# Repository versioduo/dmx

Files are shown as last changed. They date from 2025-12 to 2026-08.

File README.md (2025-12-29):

# dmx
🚥 MIDI to DMX Controller

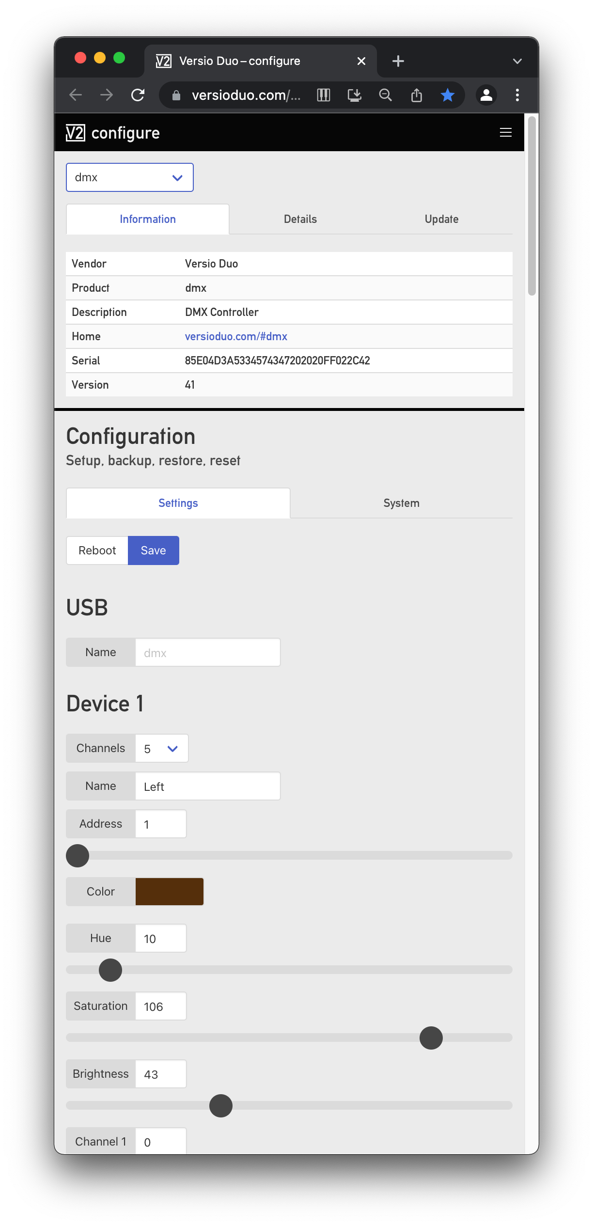
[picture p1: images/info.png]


## Configuration
Up to 16 DMX devices are mapped to 16 MIDI channels. The DMX
devices are configured by their base DMX address and the number
of DMX channels to control.

Default power-on values can be stored in the configuration. A MIDI
_System-Reset_ message will reset all devices and channels to their
configured power-on values.

For RGB devices, it is possible to use a separate set of more
intuitive CC values to control _Brightness_, _Colour_, _Saturation_;
the controller will calculate the RGB channel values accordingly.

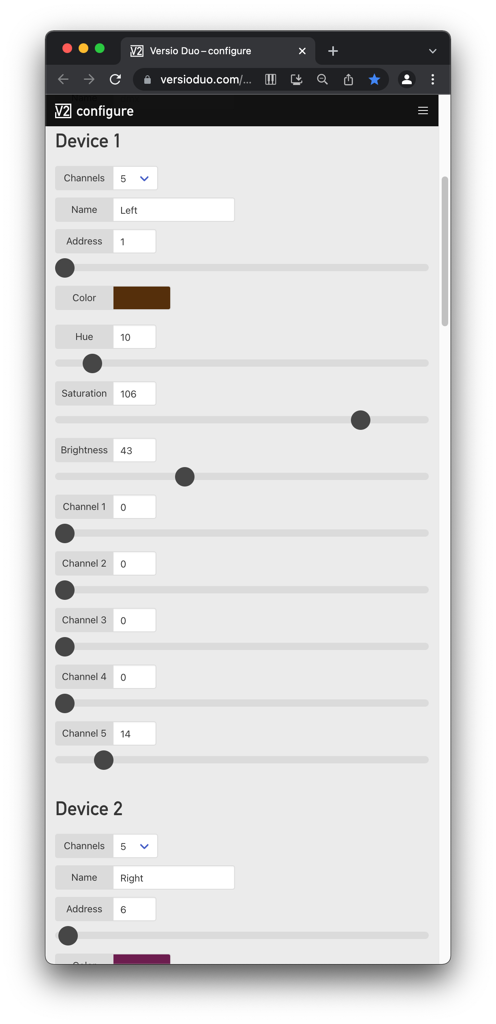
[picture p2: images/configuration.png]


## Controllers
MIDI Control Change (CC) values control the DMX channel values.

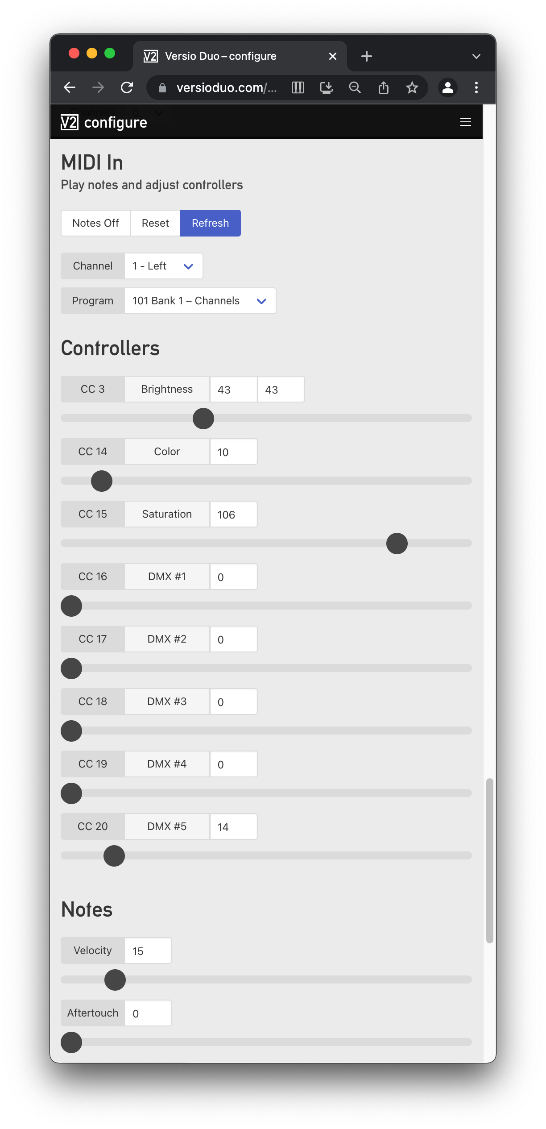
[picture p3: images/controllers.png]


## Notes
The velocity value of a note overwrites the corresponding CC value
for the duration of the note; a MIDI _Note-Off_ will reset the DMX channel
value to the current CC value. A MIDI _All-Notes-Off_ message will restore
all devices and channels to the currently configured controller values.

During an active note, channel aftertouch will change the _Brightness_,
pitch bend will change the _Colour_.

There are two programs (MIDI _Program Change_) for notes. _Channels_
maps a range of consecutive notes to DMX channels.

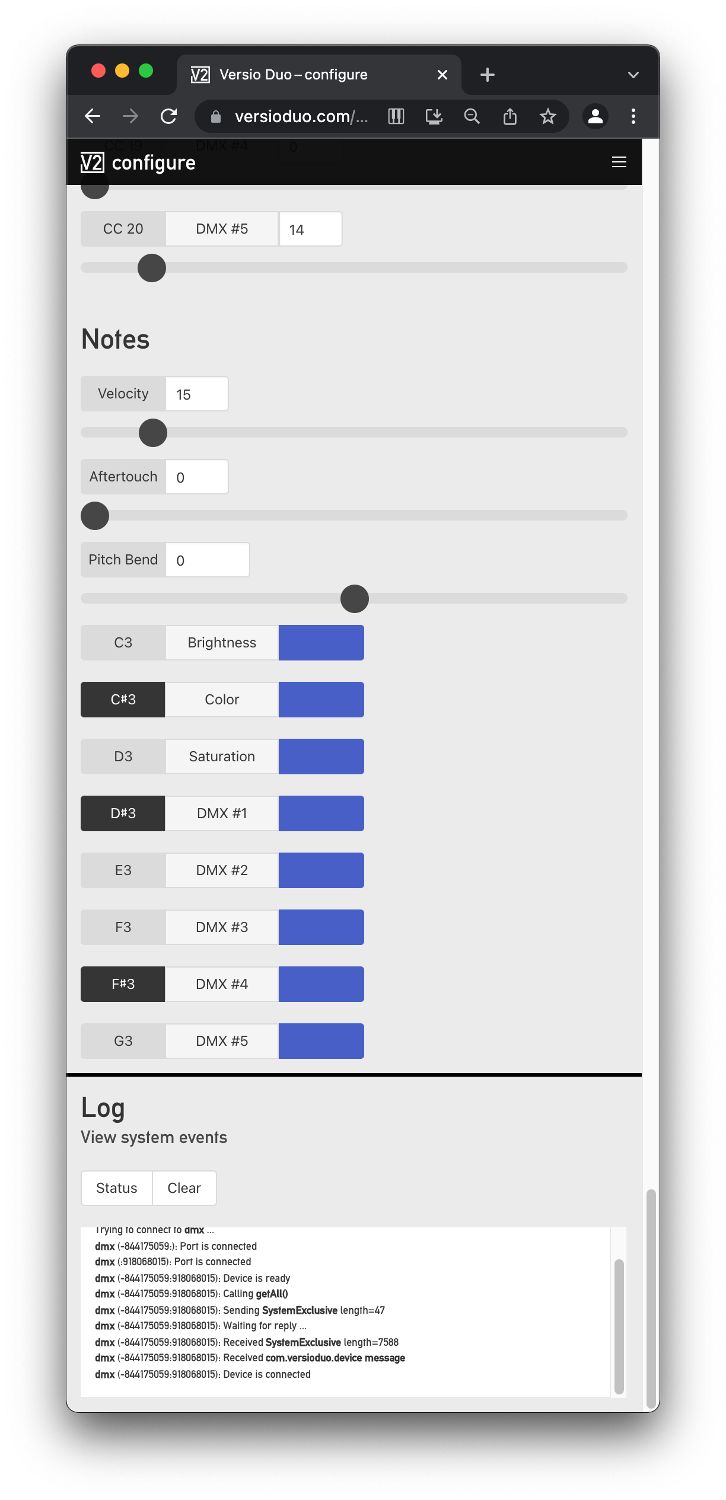
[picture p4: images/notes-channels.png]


_Brightness_ maps all received notes (the pitch is ignored) to control
only the brightness (or the first DMX channel of the device) of the DMX device.
If multiple notes are played at the same time, a MIDI _Note-Off_ will restore
the value of the earlier, still active note.

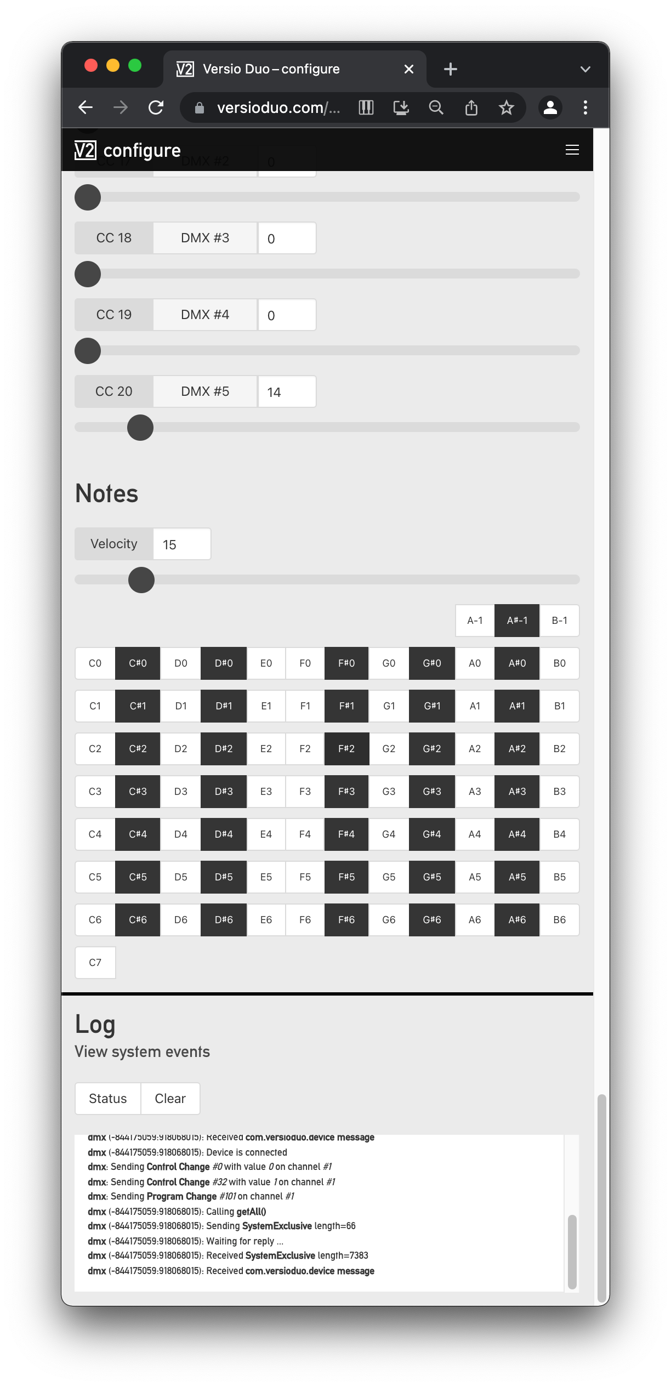
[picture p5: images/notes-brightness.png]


## Max For Live Device
An optional Ableton Max4Live [device](https://github.com/versioduo/max4live)
allows the the direct mapping from Live Automation to DMX values.

To avoid inconsistencies it will monitor the Live transport state, and update
all configured DMX channels of the current device every time _Play_ or
_Stop_ are triggered.

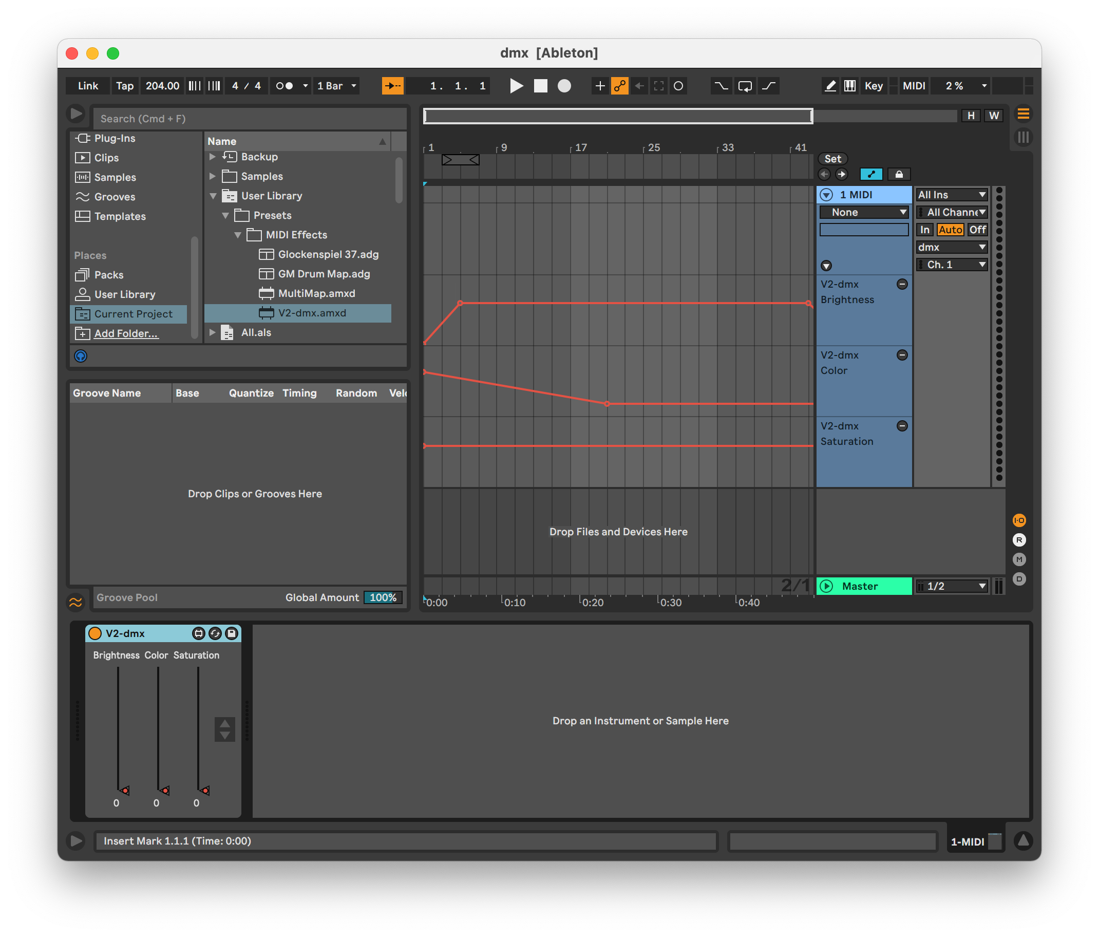
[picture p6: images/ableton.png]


## Hardware
Schematics / PCB

# Copying
Anyone can use this public domain work without having to seek authorisation, no one can ever own it.

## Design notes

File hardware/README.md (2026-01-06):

# dmx-hardware

🚥 MIDI to DMX Bridge

## Board

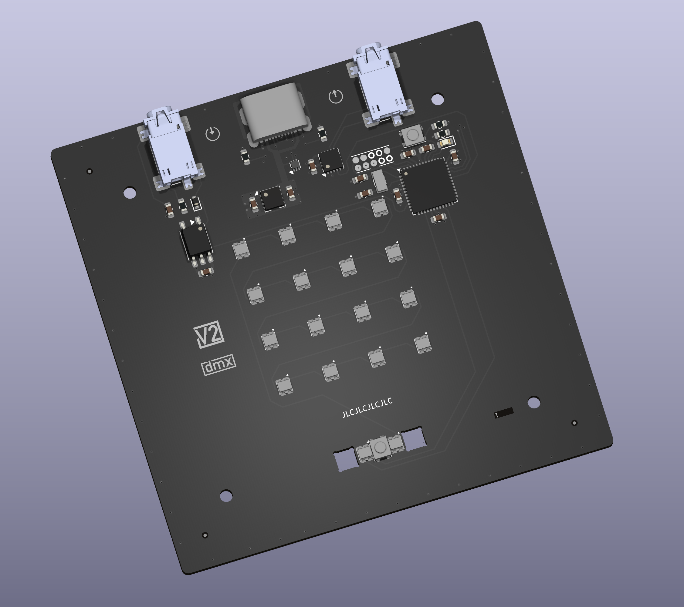
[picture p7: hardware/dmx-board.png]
board


## Schematic

[PDF](dmx.pdf)

## Bill Of Materials

[Interactive BOM](https://versioduo.com/view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)

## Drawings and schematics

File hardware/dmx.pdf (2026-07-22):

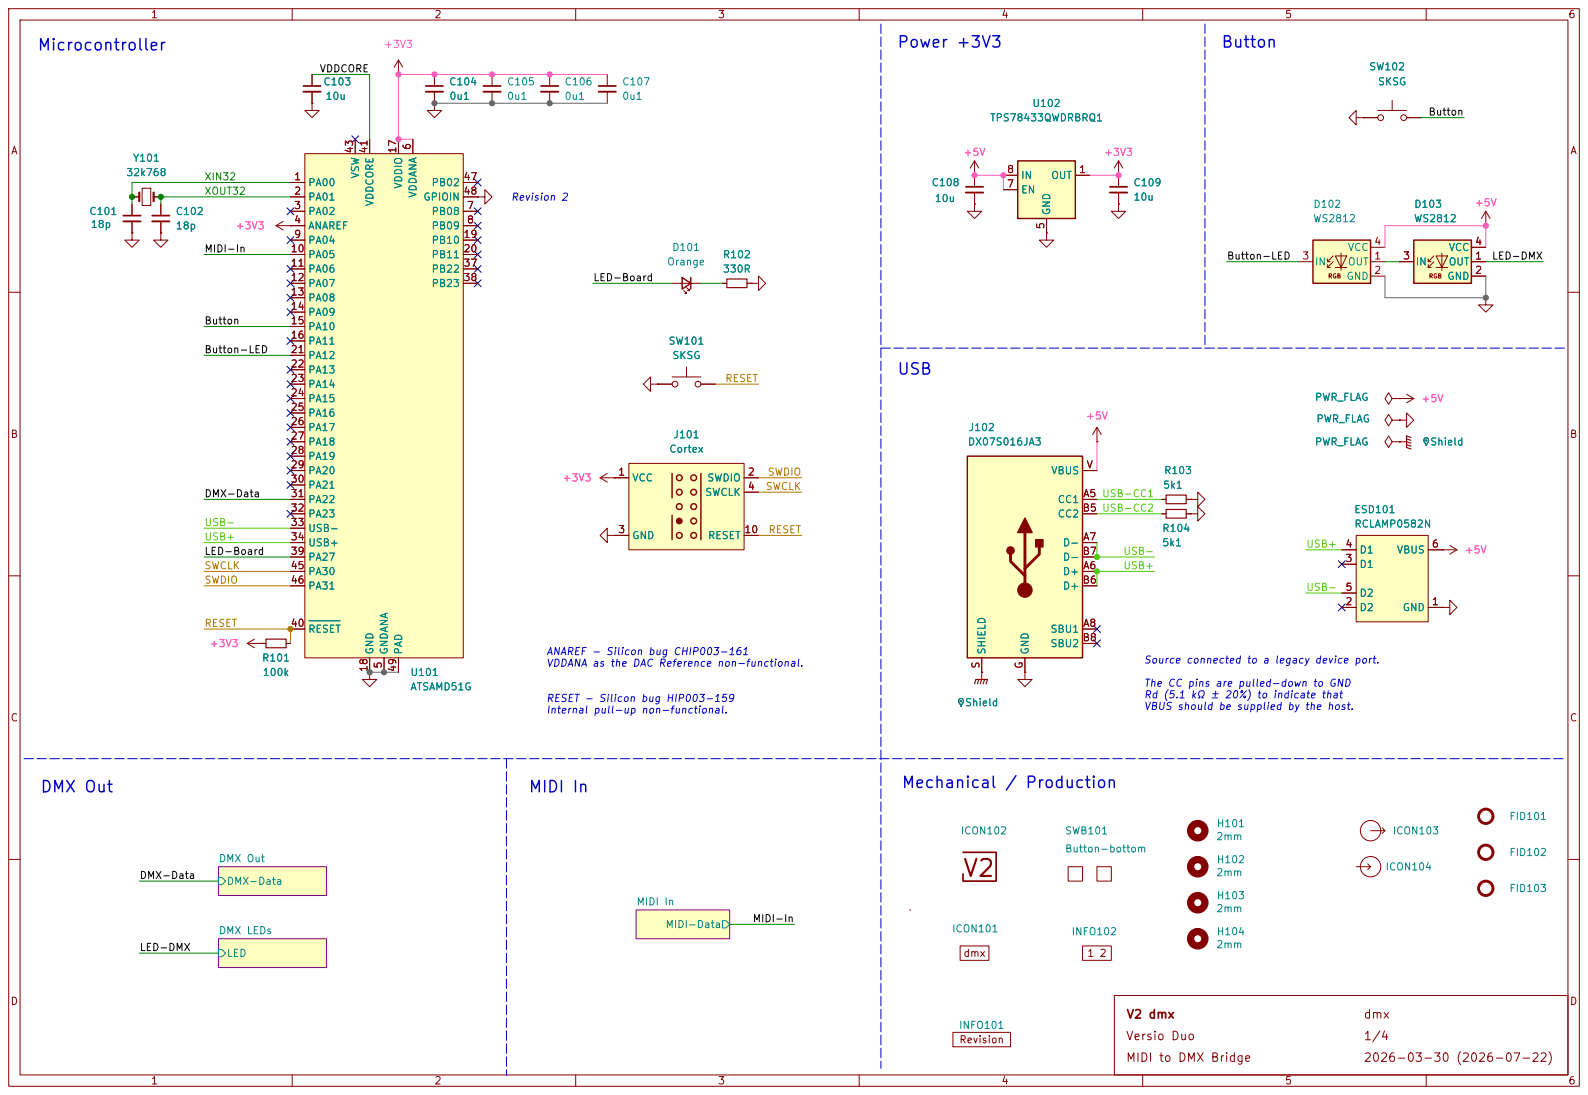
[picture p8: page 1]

Rd (5.1 kΩ ± 20%) to indicate that VBUS should be supplied by the host. Button

LED-DMX DMX-Data SWDIO

ANAREF - Silicon bug CHIP003-161
VDDANA as the DAC Reference non-functional. RESET - Silicon bug HIP003-159

Source connected to a legacy device port. The CC pins are pulled-down to GND

Internal pull-up non-functional. MIDI In

dmx MIDI-Data MIDI In DMX-Data DMX Out LED

V2 dmx
Versio Duo
MIDI to DMX Bridge

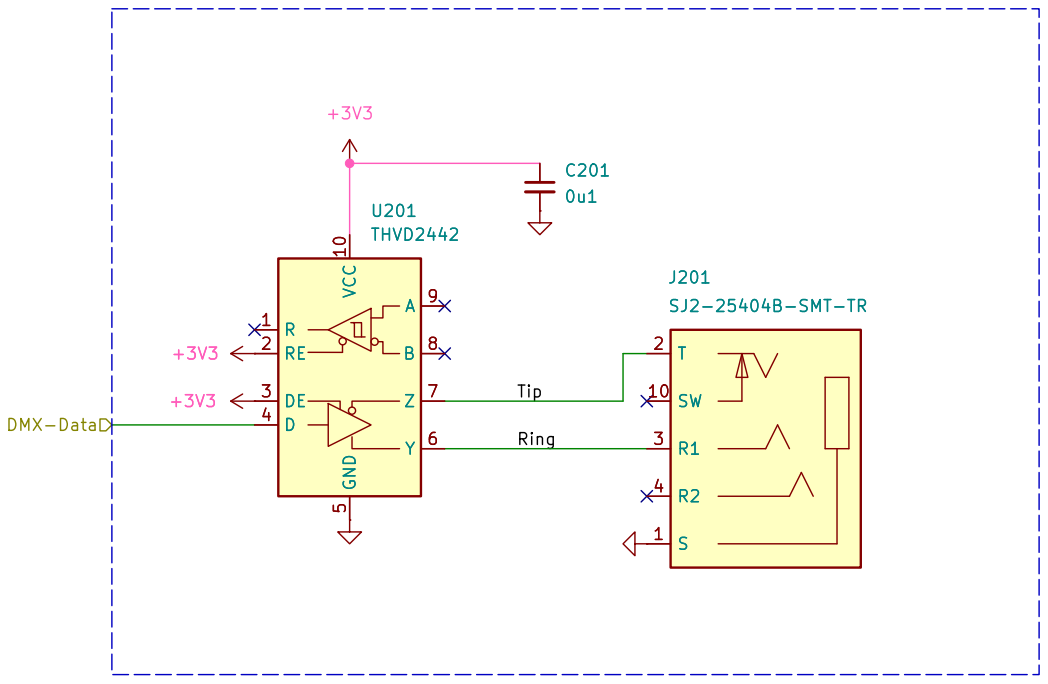
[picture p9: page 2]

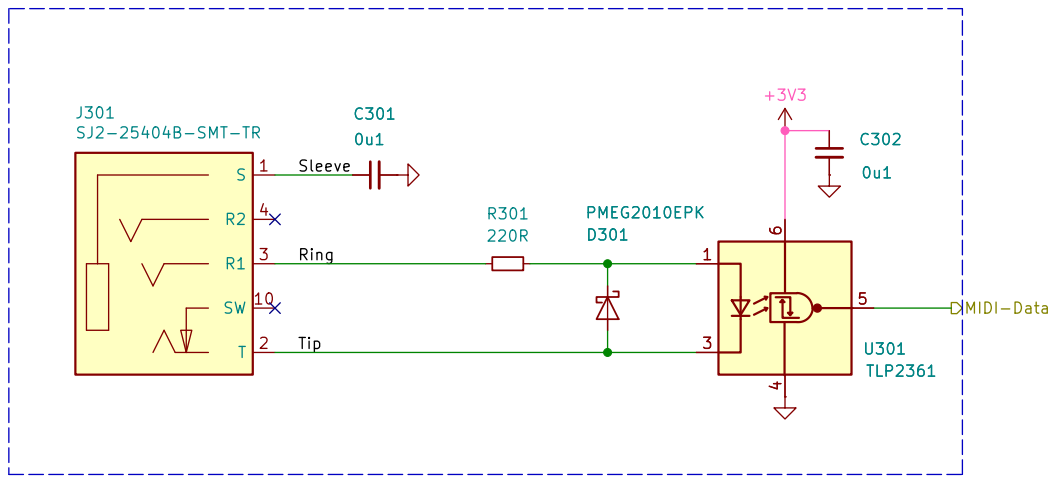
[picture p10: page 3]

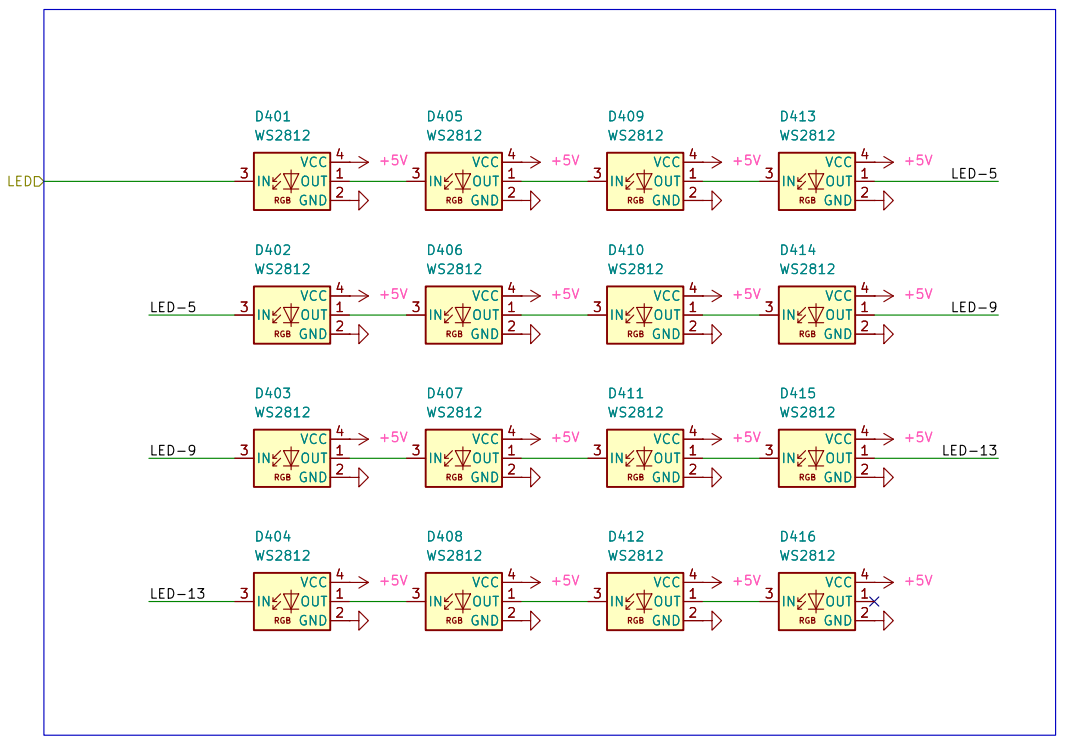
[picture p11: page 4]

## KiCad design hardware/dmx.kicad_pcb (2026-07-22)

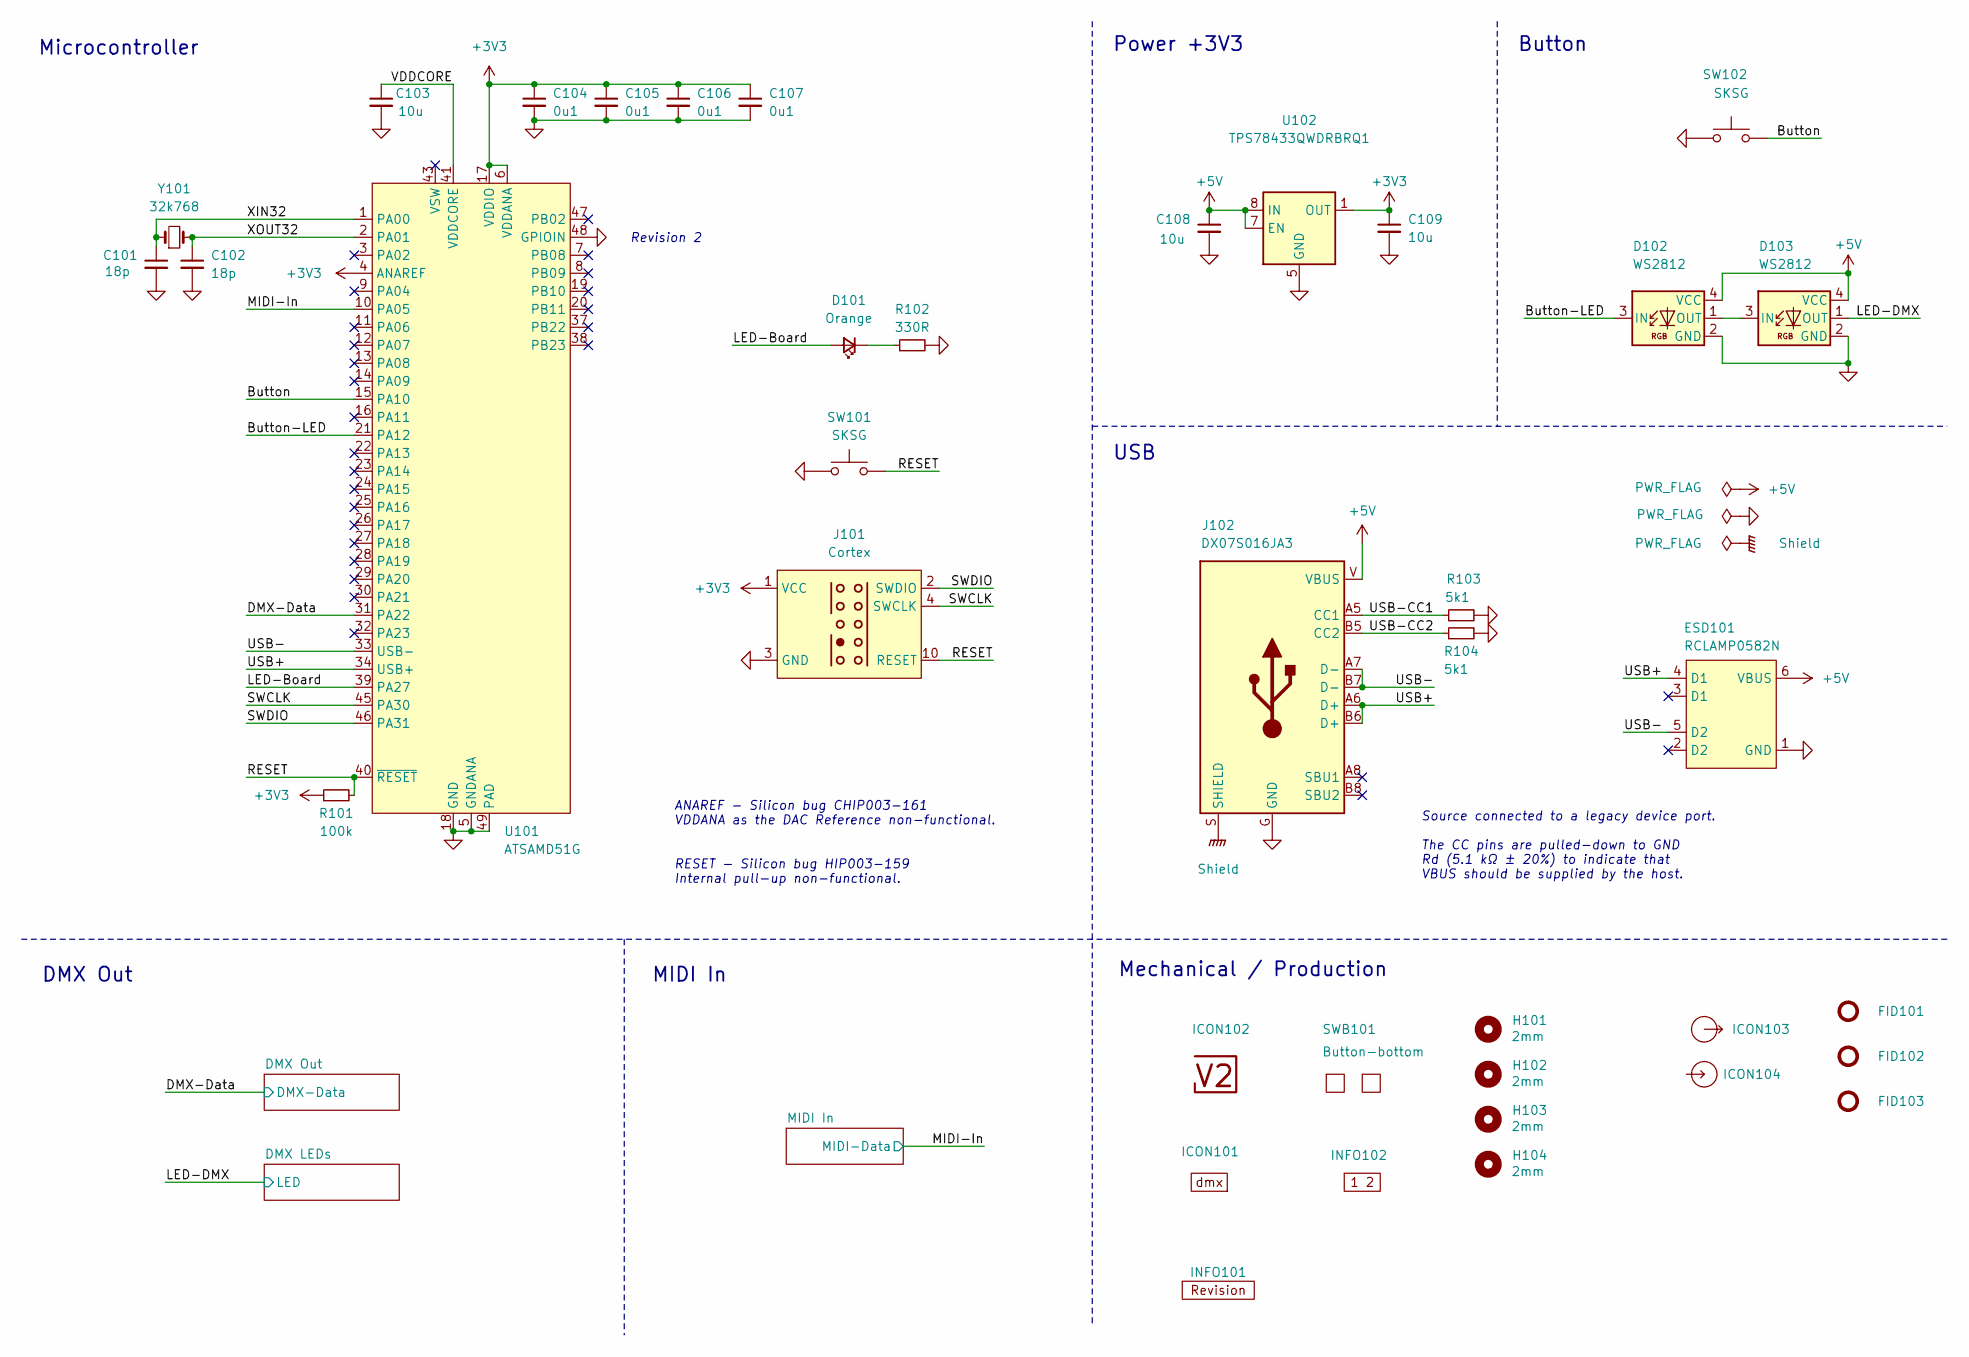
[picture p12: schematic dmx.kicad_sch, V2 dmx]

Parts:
C101, C102: 18p; C_1608; Rating 50V; Mouser 810-CGA3E2C0G1H180J
C103: 10u; C_1608; Rating 10V; Mouser 810-C1608X6S1A106M
C104, C105, C106, C107: 0u1; C_1608; Rating 50V; Mouser 810-CGA3E2X7R1H104MA
C108, C109: 10u; C_2012; Rating 25V; Mouser 810-C2012X5R1E106K
D101: Orange; LED_1608; Rating 605nm; Mouser 755-SML-D12D1WT86
D102, D103: WS2812; WS2812-2020; Rating 15mA; LCSC C965555
ESD101: RCLAMP0582N; SLP1210N6; Rating 20kV; Mouser 947-RCLAMP0582N.TCT
FID101, FID102, FID103: Fiducial_Paste; Fiducial_0.5mm_Mask1mm_Paste
H101, H102, H103, H104: 2mm; MountingHole_2mm
ICON101: Board_dmx; Board_dmx_Small
ICON102: V2-logo; Logo_Small
ICON103: Arrow_Out
ICON104: Arrow_In
INFO101: Revision
INFO102: Layer_Numbers-4
J101: Cortex
J102: DX07S016JA3; JAE_DX07S016JA3; Rating USB2.0; Mouser 656-DX07S016JA3R1500
R101: 100k; R_1608; Rating 100mW; Mouser 71-CRCW0603100KFKEAC
R102: 330R; R_1608; Rating 100mW; Mouser 71-CRCW0603330RFKEAC
R103, R104: 5k1; R_1608; Rating 100mW; Mouser 71-CRCW06035K10FKEAC
SW101, SW102: SKSG; Rating 1.6N; Mouser 688-SKSGACE010
SWB101: Button-bottom; PCB_Button-bottom
U101: ATSAMD51G; QFN-48-1EP_7x7mm_P0.5mm_EP5.45x5.45mm_ThermalVias; Rating Cortex-M4F; Mouser 556-ATSAMD51G19AMU
U102: TPS78433QWDRBRQ1; VSON-8-1_3x3mm_P0.65_EP1.65x2.4mm; Rating 300mA; Mouser 595-TPS78433QWDRBRQ1
Y101: 32k768; Crystal_SMD_3215-2Pin_3.2x1.5mm; Rating 10ppm; Mouser 815-ABS0716632.768KT

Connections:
+3V3: C104.1, C105.1, C106.1, C107.1, C109.1, J101.1 (VCC), R101.1, U101.4 (ANAREF), U101.6 (VDDANA), U101.17 (VDDIO), U101.36 (VDDIO), U101.44 (VDDIO), U102.1 (OUT); also elsewhere on the board
+5V: C108.1, D102.4 (VCC), D103.4 (VCC), ESD101.6 (VBUS), J102.V (VBUS), U102.7 (EN), U102.8 (IN); also elsewhere on the board
/Button: SW102.2, U101.15 (PA10)
/Button-LED: D102.3 (IN), U101.21 (PA12)
/DMX-Data: U101.31 (PA22); also elsewhere on the board
/LED-Board: D101.2 (A), U101.39 (PA27)
/LED-DMX: D103.1 (OUT); also elsewhere on the board
/MIDI-In: U101.10 (PA05); also elsewhere on the board
/RESET: J101.10 (RESET), R101.2, SW101.2, U101.40 (~RESET)
/SWCLK: J101.4 (SWCLK), U101.45 (PA30)
/SWDIO: J101.2 (SWDIO), U101.46 (PA31)
/Shield: J102.S (SHIELD)
/USB+: ESD101.4 (D1), J102.A6 (D+), J102.B6 (D+), U101.34 (USB+)
/USB-: ESD101.5 (D2), J102.A7 (D-), J102.B7 (D-), U101.33 (USB-)
/USB-CC1: J102.A5 (CC1), R103.1
/USB-CC2: J102.B5 (CC2), R104.1
/VDDCORE: C103.1, U101.41 (VDDCORE)
/XIN32: C101.1, U101.1 (PA00), Y101.1
/XOUT32: C102.1, U101.2 (PA01), Y101.2
GND: C101.2, C102.2, C103.2, C104.2, C105.2, C106.2, C107.2, C108.2, C109.2, D102.2 (GND), D103.2 (GND), ESD101.1 (GND), J101.3 (GND), J101.5 (GND), J102.G (GND), R102.2, R103.2, R104.2, SW101.1, SW102.1, U101.5 (GNDANA), U101.18 (GND), U101.35 (GND), U101.42 (GND), U101.48 (GPIOIN), U101.49 (PAD), U102.5 (GND), U102.9 (GND); also elsewhere on the board
unnamed: D101.1 (K), R102.1
unnamed: D102.1 (OUT), D103.3 (IN)

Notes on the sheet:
 ANAREF - Silicon bug CHIP003-161 VDDANA as the DAC Reference non-functional.
RESET -  Silicon bug HIP003-159 Internal pull-up non-functional.
 Source connected to a legacy device port. The CC pins are pulled-down to GND Rd (5.1 kΩ ± 20%) to indicate that VBUS should be supplied by the host.
Button
Revision 2
Mechanical / Production
Power +3V3
Microcontroller
USB
DMX Out
MIDI In

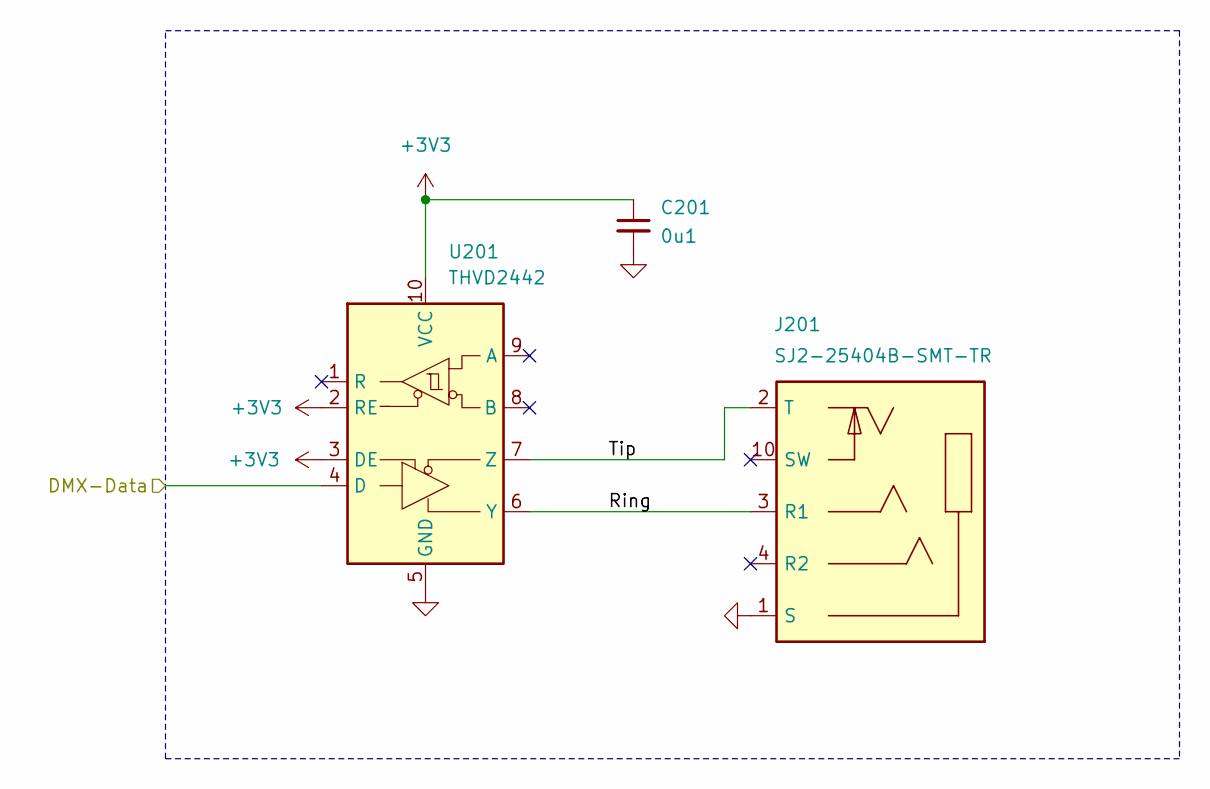
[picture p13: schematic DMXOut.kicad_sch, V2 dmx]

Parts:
C201: 0u1; C_1608; Rating 50V; Mouser 810-CGA3E2X7R1H104MA
J201: SJ2-25404B-SMT-TR; CUI_SJ2-25404B-SMT-TR; Rating 2.5mm; Mouser 490-SJ2-25404BSMT-TR
U201: THVD2442; VSON-10-4-1EP_3x3mm_P0.5mm_EP1.65x2.4mm_ThermalVias; Rating 20Mbps; Mouser 595-THVD2442DRCR

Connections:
+3V3: C201.1, U201.2 (RE), U201.3 (DE), U201.10 (VCC); also elsewhere on the board
/DMX Out/Ring: J201.3 (R1), U201.6 (Y)
/DMX Out/Tip: J201.2 (T), U201.7 (Z)
/DMX-Data: U201.4 (D); also elsewhere on the board
GND: C201.2, J201.1 (S), U201.5 (GND), U201.11 (GND); also elsewhere on the board

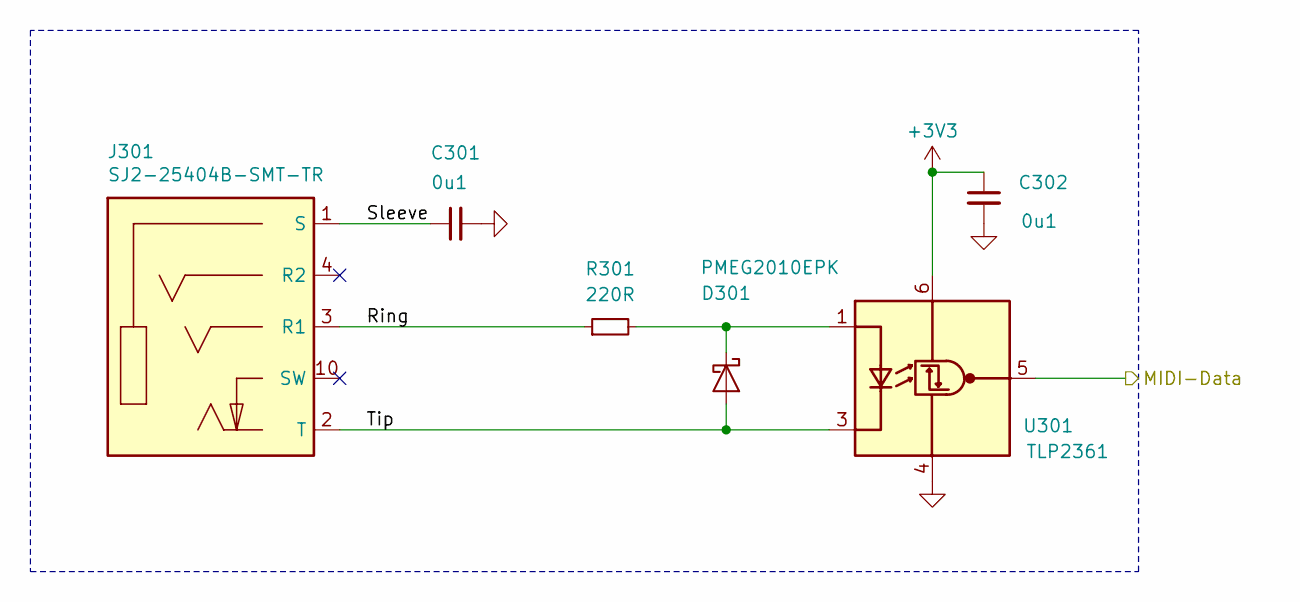
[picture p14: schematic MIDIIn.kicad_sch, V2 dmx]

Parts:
C301, C302: 0u1; C_1608; Rating 50V; Mouser 810-CGA3E2X7R1H104MA
D301: PMEG2010EPK; D_SOD-1608; Rating 20V; Mouser 771-PMEG2010EPK
J301: SJ2-25404B-SMT-TR; CUI_SJ2-25404B-SMT-TR; Rating 2.5mm; Mouser 490-SJ2-25404BSMT-TR
R301: 220R; R_1608; Rating 330mW; Mouser 71-CRCW0603220RFKEAH
U301: TLP2361; SO-5-6_4.55x3.7mm_P1.27mm; Rating 15Mbps; Mouser 757-TLP2361TPRE

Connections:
+3V3: C302.1, U301.6 (VDD); also elsewhere on the board
/MIDI In/Ring: J301.3 (R1), R301.1
/MIDI In/Sleeve: C301.1, J301.1 (S)
/MIDI In/Tip: D301.2 (A), J301.2 (T), U301.3 (K)
/MIDI-In: U301.5 (VO); also elsewhere on the board
GND: C301.2, C302.2, U301.4 (GND); also elsewhere on the board
unnamed: D301.1 (K), R301.2, U301.1 (A)

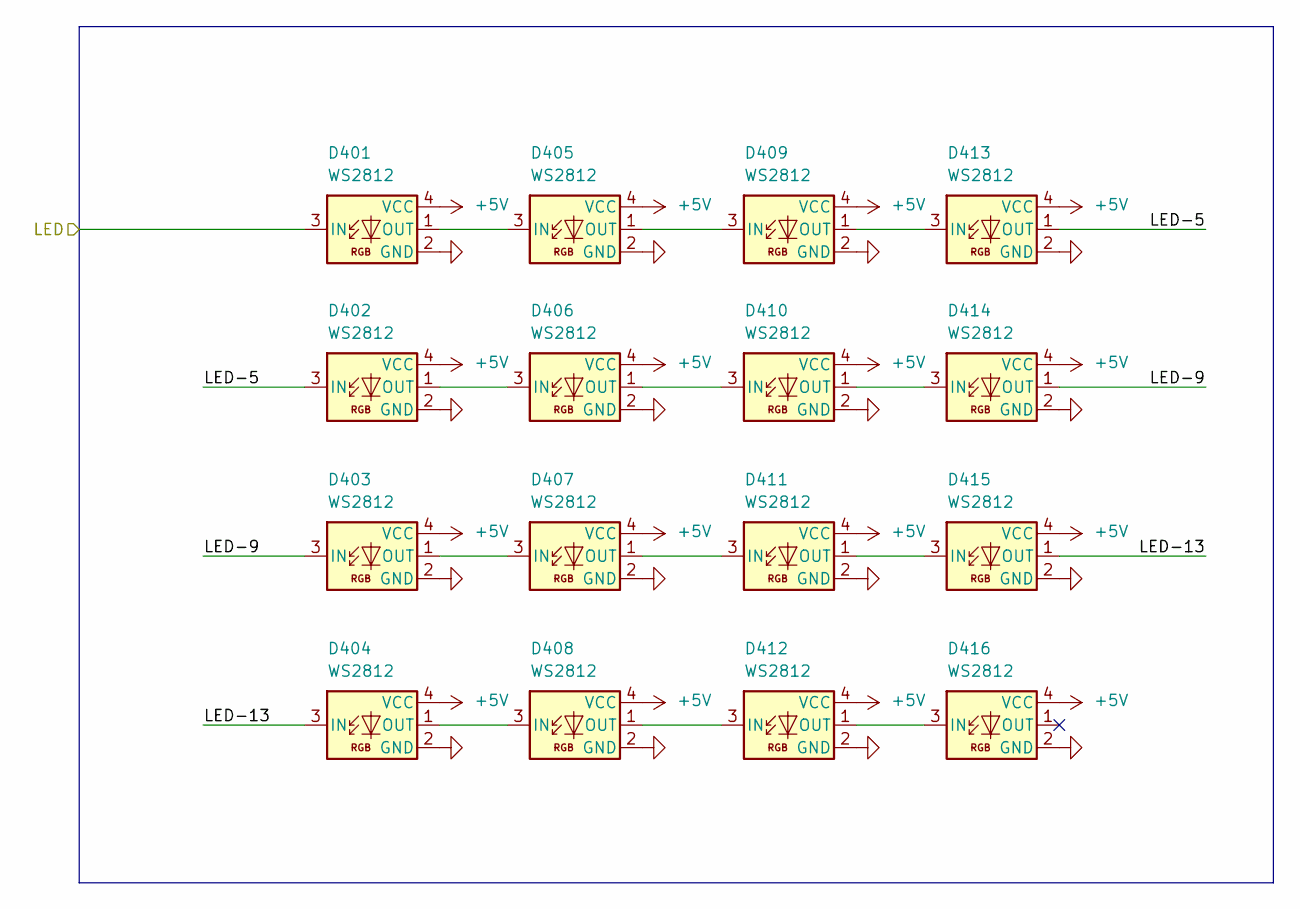
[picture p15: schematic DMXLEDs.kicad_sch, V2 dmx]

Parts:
D401, D402, D403, D404, D405, D406, D407, D408, D409, D410, D411, D412, D413, D414, D415, D416: WS2812; WS2812-2020; Rating 15mA; LCSC C965555

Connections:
+5V: D401.4 (VCC), D402.4 (VCC), D403.4 (VCC), D404.4 (VCC), D405.4 (VCC), D406.4 (VCC), D407.4 (VCC), D408.4 (VCC), D409.4 (VCC), D410.4 (VCC), D411.4 (VCC), D412.4 (VCC), D413.4 (VCC), D414.4 (VCC), D415.4 (VCC), D416.4 (VCC); also elsewhere on the board
/DMX LEDs/LED-5: D402.3 (IN), D413.1 (OUT)
/DMX LEDs/LED-9: D403.3 (IN), D414.1 (OUT)
/DMX LEDs/LED-13: D404.3 (IN), D415.1 (OUT)
/LED-DMX: D401.3 (IN); also elsewhere on the board
GND: D401.2 (GND), D402.2 (GND), D403.2 (GND), D404.2 (GND), D405.2 (GND), D406.2 (GND), D407.2 (GND), D408.2 (GND), D409.2 (GND), D410.2 (GND), D411.2 (GND), D412.2 (GND), D413.2 (GND), D414.2 (GND), D415.2 (GND), D416.2 (GND); also elsewhere on the board
unnamed: D401.1 (OUT), D405.3 (IN)
unnamed: D402.1 (OUT), D406.3 (IN)
unnamed: D403.1 (OUT), D407.3 (IN)
unnamed: D404.1 (OUT), D408.3 (IN)
unnamed: D405.1 (OUT), D409.3 (IN)
unnamed: D406.1 (OUT), D410.3 (IN)
unnamed: D407.1 (OUT), D411.3 (IN)
unnamed: D408.1 (OUT), D412.3 (IN)
unnamed: D409.1 (OUT), D413.3 (IN)
unnamed: D410.1 (OUT), D414.3 (IN)
unnamed: D411.1 (OUT), D415.3 (IN)
unnamed: D412.1 (OUT), D416.3 (IN)

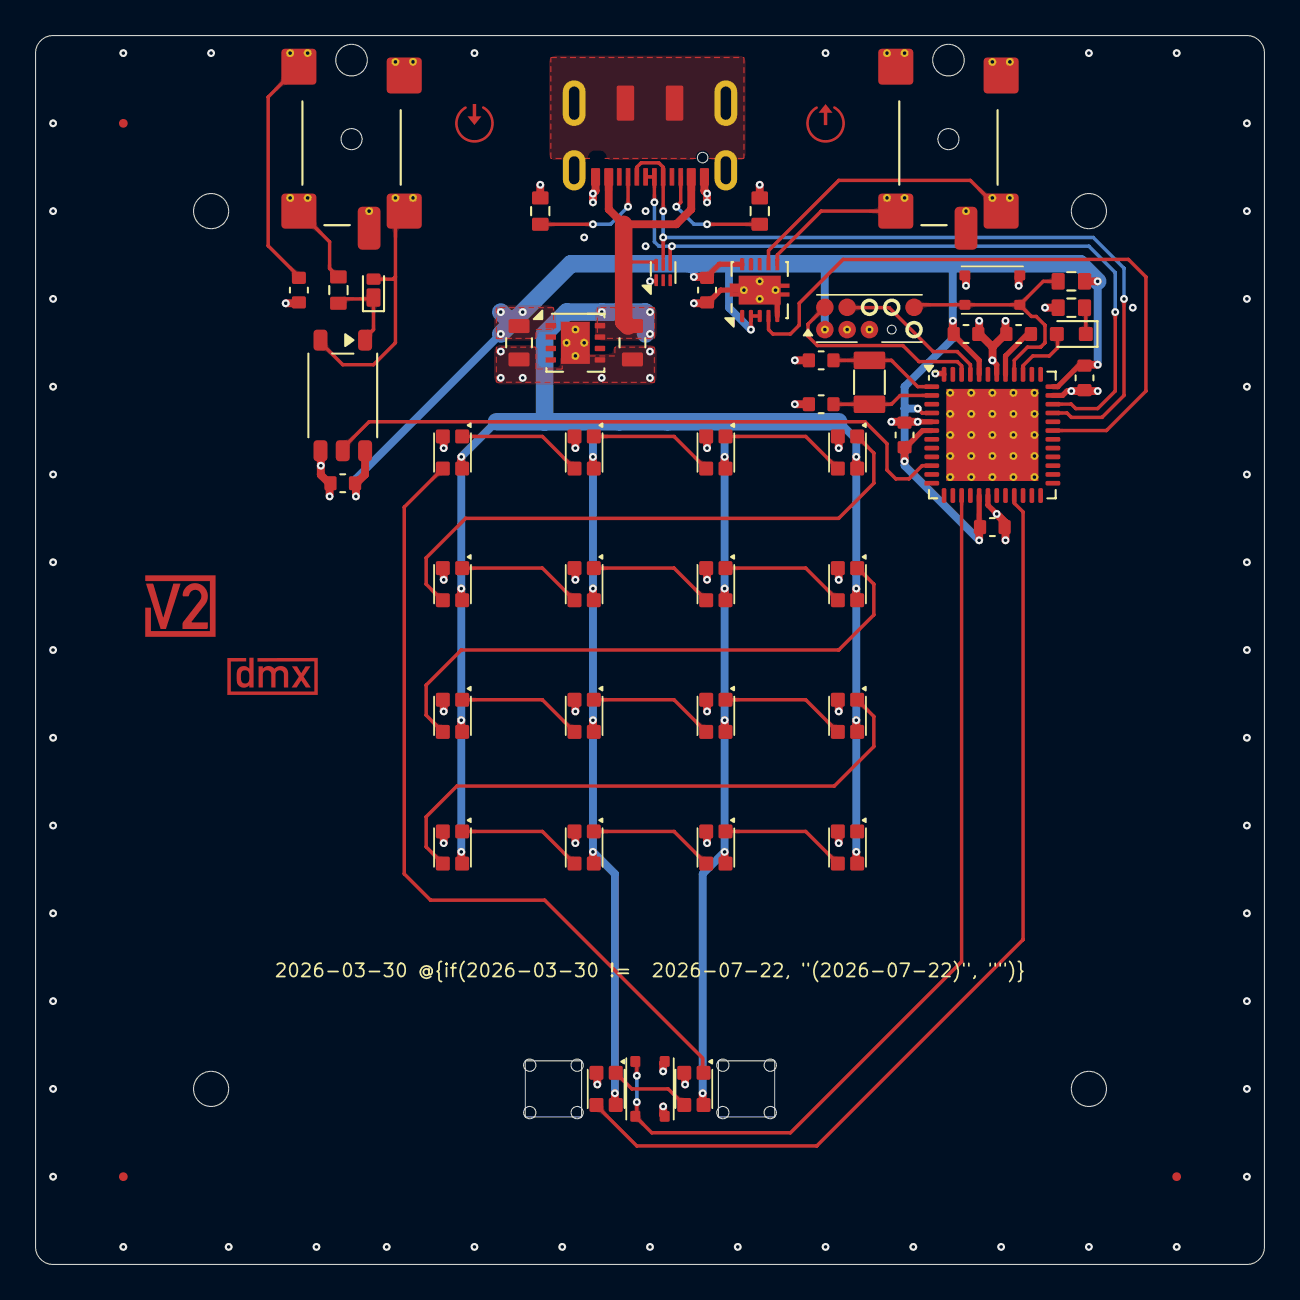
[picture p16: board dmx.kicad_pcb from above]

Board: 4 copper layers, 70.0 x 70.0 mm, 63 parts (0 on the bottom side), 42 nets.

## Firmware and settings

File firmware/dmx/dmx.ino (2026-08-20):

#include <V2Buttons.h>
#include <V2DMX.h>
#include <V2Device.h>
#include <V2LED.h>
#include <V2MIDI.h>
#include <V2Music.h>

namespace {
  V2Device::Info       Info{V2DeviceInfo("com.versioduo.dmx", 63, "versioduo:samd:dmx")};
  V2LED::WS2812<18>    LED(PIN_LED_WS2812, sercom2, SPI_PAD_0_SCK_1, PIO_SERCOM);
  V2DMX                DMX(PIN_DMX_TX, sercom3, SPI_PAD_0_SCK_1, PIO_SERCOM);
  V2MIDI::SerialDevice MIDISerial(&SerialMIDI, "serial");

  class Device : public V2Device {
  public:
    Device() : V2Device() {
      metadata.vendor      = "Versio Duo";
      metadata.product     = "V2 dmx";
      metadata.description = "MIDI to DMX Bridge";
      metadata.home        = "https://versioduo.com/#dmx";
      help.device          = "Up to 16 DMX devices are mapped to 16 MIDI channels. The DMX devices are configured by "
                             "their base DMX address and the number of DMX channels to control.\n"
                             "Control Change messages are mapped to DMX channel values. Notes are used to temporarily "
                             "overwrite a control value for the duration of the note.\n"
                             "For RGB devices it is possible to use a separate set of more intuitive CC values to "
                             "control Brightness, Colour, Saturation; the controller will calculate the RGB channel "
                             "values accordingly.";
      help.configuration   = "Default power-on values can be configured. An AllNotesOff control message will "
                             "clear all power-on settings. A MIDI System-Reset message will reset all DMX devices "
                             "and channels to their configured power-on values.";
      system.download      = "https://versioduo.com/download";
      system.configure     = "https://versioduo.com/configure";
      usb.ports.standard   = 0;
      configuration        = {.size{sizeof(config)}, .data{&config}};
    }

    enum class CC {
      Brightness = V2MIDI::CC::Controller3,
      Colour     = V2MIDI::CC::Controller14,
      Saturation = V2MIDI::CC::Controller15,

      EnvelopeAttack  = V2MIDI::CC::SoundController4,
      EnvelopeRelease = V2MIDI::CC::SoundController3,
    };

    enum class State { Off, Config, MIDI, _count };
    enum class Program { Brightness, Channels, _count };

    // Config, written to EEPROM
    struct {
      struct {
        char     name[32];
        uint16_t address;
        uint16_t count;
        uint8_t  h;
        uint8_t  s;
        uint8_t  v;
        uint8_t  channels[32];
      } devices[16];
    } config{.devices{
      {.name{"Alfa"}, .address{0 * 5}, .count{3}},
      {.name{"Berta"}, .address{1 * 5}},
      {.name{"Charlotte"}, .address{2 * 5}},
      {.name{"David"}, .address{3 * 5}},
      {.name{"Eva"}, .address{4 * 5}},
      {.name{"Friedrich"}, .address{5 * 5}},
      {.name{"Gustav"}, .address{6 * 5}},
      {.name{"Heinrich"}, .address{7 * 5}},
      {.name{"Ida"}, .address{8 * 32}},
      {.name{"Jakob"}, .address{9 * 5}},
      {.name{"Katharina"}, .address{10 * 5}},
      {.name{"Ludwig"}, .address{11 * 5}},
      {.name{"Marie"}, .address{12 * 5}},
      {.name{"Nathan"}, .address{13 * 5}},
      {.name{"Otto"}, .address{14 * 5}},
      {.name{"Paula"}, .address{15 * 5}},
    }};

    void readConfiguration() {
      bool values{};

      for (uint8_t ch = 0; ch < 16; ch++) {
        // Set default values from EEPROM.
        if (config.devices[ch].count >= 3 && config.devices[ch].v > 0) {
          _devices[ch].cc.h = (float)config.devices[ch].h / 127.f * 360.f;
          _devices[ch].cc.s = (float)config.devices[ch].s / 127.f;
          _devices[ch].cc.v.setFraction((uint8_t)CC::Brightness, (float)config.devices[ch].v / 127.f);
          _devices[ch].mode = Mode::HSV;

          for (uint8_t i = 3; i < config.devices[ch].count; i++)
            _devices[ch].cc.channels[i] = config.devices[ch].channels[i];
          values = true;

        } else {
          for (uint8_t i = 0; i < config.devices[ch].count; i++) {
            if (config.devices[ch].channels[i] == 0)
              continue;

            _devices[ch].cc.channels[i] = config.devices[ch].channels[i];
            values                      = true;
          }
        }

        updateChannel(ch);
      }

      if (values)
        setState(State::Config);
    }

    void allNotesOff() {
      if (_force.trigger()) {
        reset();
        return;
      }

      for (uint8_t ch = 0; ch < 16; ch++) {
        _devices[ch].note = {};
        _devices[ch].note.playing.reset();
        updateChannel(ch);
      }
    }

    void setState(State state) {
      _state = state;

      switch (_state) {
        case State::Off:
          LED.hsv({V2Colour::Yellow, 1, 0.1}, 0, 2);
          break;

        case State::Config:
          LED.hsv({V2Colour::Green, 1, 0.4}, 0, 2);
          break;

        case State::MIDI:
          LED.hsv({V2Colour::Cyan, 1, 0.4}, 0, 2);
          break;
      }
    }

    void toggleState() {
      switch (_state) {
        case State::Off:
          readConfiguration();
          break;

        case State::Config:
        case State::MIDI:
          reset();
          break;
      }
    }

  private:
    uint32_t            _usec{};
    V2Music::ForcedStop _force;
    State               _state{};
    const char*         _programNames[(uint8_t)Program::_count]{"Brightness", "Channels"};

    // The current mode of the first three channels;
    enum class Mode { Channels, HSV };

    struct {
      Program  program;
      uint16_t bank;
      Mode     mode;

      struct {
        float                                               h;
        float                                               s;
        V2MIDI::CC::HighResolution<(uint8_t)CC::Brightness> v;
        uint8_t                                             channels[32];
      } cc;

      struct {
        V2Music::Playing<88> playing;
        float                aftertouch;
        float                pitchbend;

        struct {
          float attack;
          float release;
        } envelope;

        float   h;
        float   s;
        float   v;
        uint8_t channels[32];
      } note;

      struct {
        float h;
        float s;
        float v;
        float vTarget;

        struct {
          bool     active;
          float    speed;
          uint32_t usec;
        } fade;
      } now;
    } _devices[16]{};

    // The currently selected channel in the user interface. Only a single channel
    // is exported with getAll() to reduce the size of the reply message.
    uint8_t _currentChannel{};

    void handleReset() override {
      LED.reset();
      DMX.reset();
      _force.reset();

      _currentChannel = 0;
      for (uint8_t i = 0; i < 16; i++)
        _devices[i] = {};

      setState(State::Off);
    }

    void handleLoop() override {
      if (V2Base::getUsecSince(_usec) < 25 * 1000)
        return;

      _usec = V2Base::getUsec();

      for (uint8_t ch = 0; ch < 16; ch++) {
        if (!_devices[ch].now.fade.active)
          continue;

        const float passedSec      = (float)V2Base::getUsecSince(_devices[ch].now.fade.usec) / 1000000.f;
        _devices[ch].now.fade.usec = V2Base::getUsec();

        const float step     = _devices[ch].now.fade.speed * passedSec;
        const float distance = _devices[ch].now.vTarget - _devices[ch].now.v;
        if (step >= fabs(distance)) {
          _devices[ch].now.v           = _devices[ch].now.vTarget;
          _devices[ch].now.fade.active = false;

        } else {
          _devices[ch].now.v += copysignf(step, distance);
        }

        updateDMXHSV(ch);
      }
    }

    void setMode(uint8_t channel, Mode mode) {
      _devices[channel].mode = mode;

      switch (mode) {
        case Mode::Channels:
          _devices[channel].cc.h = 0;
          _devices[channel].cc.s = 0;
          _devices[channel].cc.v.set((uint8_t)CC::Brightness, 0);
          break;

        case Mode::HSV:
          _devices[channel].cc.channels[0] = 0;
          _devices[channel].cc.channels[1] = 0;
          _devices[channel].cc.channels[2] = 0;
          break;
      }
    }

    void setDMX(uint8_t channel, uint8_t address, float fraction) {
      DMX.channel(config.devices[channel].address + address, roundf(fraction * 255.f));
    }

    void updateDMXHSV(uint8_t channel) {
      LED.hsv({_devices[channel].now.h, _devices[channel].now.s, _devices[channel].now.v}, 2 + channel);

      uint8_t r, g, b;
      V2Colour::HSVtoRGB(_devices[channel].now.h, _devices[channel].now.s, _devices[channel].now.v, r, g, b);
      DMX.channel(config.devices[channel].address + 0, r);
      DMX.channel(config.devices[channel].address + 1, g);
      DMX.channel(config.devices[channel].address + 2, b);
    }

    // Update the DMX channels, possibly overwriting the CC values for the duration
    // of playing notes. The brightness and colour of playing notes are modulated by
    // aftertouch and pitch bend.
    void updateHSV(uint8_t channel) {
      bool note{};

      if (_devices[channel].note.h > 0.f) {
        _devices[channel].now.h = _devices[channel].note.h;
        note                    = true;

      } else {
        _devices[channel].now.h = _devices[channel].cc.h;
      }

      if (_devices[channel].note.s > 0.f) {
        _devices[channel].now.s = _devices[channel].note.s;
        note                    = true;

      } else {
        _devices[channel].now.s = _devices[channel].cc.s;
      }

      if (_devices[channel].note.v > 0.f) {
        _devices[channel].now.vTarget = _devices[channel].note.v;
        note                          = true;

      } else {
        _devices[channel].now.vTarget = _devices[channel].cc.v.getFraction();
      }

      if (note) {
        _devices[channel].now.h += (_devices[channel].note.pitchbend * 180.f);
        if (_devices[channel].now.h > 360.f) {
          _devices[channel].now.h -= 360.f;
        }

        else if (_devices[channel].now.h < 0.f) {
          _devices[channel].now.h += 360.f;
        }

        if (_devices[channel].note.aftertouch > 0.f)
          _devices[channel].now.vTarget = _devices[channel].note.aftertouch;
      }

      // Set the values immediately, loop() will do the fading if needed.
      if (!_devices[channel].now.fade.active) {
        _devices[channel].now.v = _devices[channel].now.vTarget;
        updateDMXHSV(channel);
      }
    }

    void updateChannel(uint8_t channel) {
      switch (_devices[channel].mode) {
        case Mode::Channels:
          // A single-channel device, the brightness note sets the channel value.
          if (config.devices[channel].count == 1 && _devices[channel].note.v > 0.f) {
            setDMX(channel, 0, _devices[channel].note.v);
            break;
          }

          for (uint8_t i = 0; i < config.devices[channel].count; i++)
            if (_devices[channel].note.channels[i] > 0)
              setDMX(channel, i, (float)_devices[channel].note.channels[i] / 127.f);

            else
              setDMX(channel, i, (float)_devices[channel].cc.channels[i] / 127.f);
          break;

        case Mode::HSV:
          updateHSV(channel);

          for (uint8_t i = 3; i < config.devices[channel].count; i++)
            if (_devices[channel].note.channels[i] > 0)
              setDMX(channel, i, (float)_devices[channel].note.channels[i] / 127.f);

            else
              setDMX(channel, i, (float)_devices[channel].cc.channels[i] / 127.f);
          break;
      }
    }

    void setEnvelope(uint8_t channel) {
      // Number of seconds to transition the full range.
      const float durationSec = 5;

      if (_devices[channel].note.v > 0.f && _devices[channel].note.envelope.attack > 0.f) {
        _devices[channel].now.fade.usec   = V2Base::getUsec();
        const float speedFraction         = powf(_devices[channel].note.envelope.attack, 2);
        _devices[channel].now.fade.speed  = 1.f / (durationSec * speedFraction);
        _devices[channel].now.fade.active = true;

      } else if (_devices[channel].note.v <= 0.f && _devices[channel].note.envelope.release > 0.f) {
        _devices[channel].now.fade.usec   = V2Base::getUsec();
        const float speedFraction         = powf(_devices[channel].note.envelope.release, 2);
        _devices[channel].now.fade.speed  = 1.f / (durationSec * speedFraction);
        _devices[channel].now.fade.active = true;

      } else {
        _devices[channel].now.fade.active = false;
      }
    }

    // Notes temporarily overwrite the values set by the controllers. The Note-Off will
    // restore the controller value.
    void handleNote(uint8_t channel, uint8_t note, uint8_t velocity) override {
      switch (_devices[channel].program) {
        case Program::Brightness:
          if (note < V2MIDI::A(-1))
            return;

          if (note >= V2MIDI::A(-1) + 88)
            return;

          _devices[channel].note.playing.update(note, velocity);
          // Restore previous note.
          if (velocity == 0) {
            uint8_t n;
            uint8_t v;
            if (_devices[channel].note.playing.getLast(n, v))
              velocity = v;
          }

          _devices[channel].note.v = (float)velocity / 127.f;
          setEnvelope(channel);
          updateChannel(channel);
          break;

        case Program::Channels: {
          switch (note) {
            case V2MIDI::C(3):
              if (config.devices[channel].count >= 3) {
                _devices[channel].note.v = (float)velocity / 127.f;
                setMode(channel, Mode::HSV);
                setEnvelope(channel);
                updateChannel(channel);
              }
              break;

            case V2MIDI::Cs(3):
              if (config.devices[channel].count >= 3) {
                _devices[channel].note.h = (float)velocity / 127.f * 360.f;
                setMode(channel, Mode::HSV);
                updateChannel(channel);
              }
              break;

            case V2MIDI::D(3):
              if (config.devices[channel].count >= 3) {
                _devices[channel].note.s = (float)velocity / 127.f;
                setMode(channel, Mode::HSV);
                updateChannel(channel);
              }
              break;

            case V2MIDI::Ds(3)... V2MIDI::Ds(3) + 31: {
              const uint8_t address = note - V2MIDI::Ds(3);
              if (address < config.devices[channel].count) {
                _devices[channel].note.channels[address] = velocity;
                updateChannel(channel);
              }
            } break;
          }
        } break;
      }

      setState(State::MIDI);
    }

    void handleNoteOff(uint8_t channel, uint8_t note, uint8_t velocity) override {
      handleNote(channel, note, 0);
    }

    void handleProgramChange(uint8_t channel, uint8_t program) override {
      if (program != V2MIDI::GM::Program::FX5Brightness)
        return;

      if (_devices[channel].bank >= (uint8_t)Program::_count)
        return;

      _devices[channel].program = (Program)_devices[channel].bank;
      _devices[channel].note.playing.reset();
    }

    void handleControlChange(uint8_t channel, uint8_t controller, uint8_t value) override {
      switch (controller) {
        case V2MIDI::CC::BankSelect:
          _devices[channel].bank = value << 7;
          break;

        case V2MIDI::CC::BankSelectLSB:
          _devices[channel].bank &= 0xff00;
          _devices[channel].bank |= value;
          break;

        case V2MIDI::CC::AllSoundOff:
        case V2MIDI::CC::AllNotesOff:
          allNotesOff();
          break;

        case (uint8_t)CC::Brightness:
        case V2MIDI::CC::ControllerLSB + (uint8_t)CC::Brightness:
          if (config.devices[channel].count < 3)
            break;

          if (!_devices[channel].cc.v.setByte(controller, value))
            break;

          setMode(channel, Mode::HSV);
          updateChannel(channel);
          break;

        case (uint8_t)CC::Colour:
          if (config.devices[channel].count < 3)
            break;

          _devices[channel].cc.h = (float)value / 127.f * 360.f;
          setMode(channel, Mode::HSV);
          updateChannel(channel);
          break;

        case (uint8_t)CC::Saturation:
          if (config.devices[channel].count < 3)
            break;

          _devices[channel].cc.s = (float)value / 127.f;
          setMode(channel, Mode::HSV);
          updateChannel(channel);
          break;

        case (uint8_t)CC::EnvelopeAttack:
          _devices[channel].note.envelope.attack = (float)value / 127.f;
          break;

        case (uint8_t)CC::EnvelopeRelease:
          _devices[channel].note.envelope.release = (float)value / 127.f;
          break;

        case V2MIDI::CC::GeneralPurpose1... V2MIDI::CC::GeneralPurpose1 + 15: {
          const uint8_t address                  = controller - V2MIDI::CC::GeneralPurpose1;
          _devices[channel].cc.channels[address] = value;
          if (address <= 2)
            setMode(channel, Mode::Channels);
          updateChannel(channel);
        } break;

        case V2MIDI::CC::Controller102... V2MIDI::CC::Controller102 + 15: {
          const uint8_t address                  = 16 + (controller - V2MIDI::CC::Controller102);
          _devices[channel].cc.channels[address] = value;
          updateChannel(channel);
        } break;
      }

      setState(State::MIDI);
    }

    void handleAftertouchChannel(uint8_t channel, uint8_t pressure) override {
      _devices[channel].note.aftertouch = (float)pressure / 127.f;
      updateChannel(channel);
    }

    void handleAftertouch(uint8_t channel, uint8_t note, uint8_t pressure) override {
      switch (_devices[channel].program) {
        case Program::Brightness:
          if (note < V2MIDI::A(-1))
            break;

          if (note >= V2MIDI::A(-1) + 88)
            break;

          handleAftertouchChannel(channel, pressure);
          break;

        case Program::Channels:
          if (note != V2MIDI::C(3))
            break;

          handleAftertouchChannel(channel, pressure);
          break;
      }
    }

    void handlePitchBend(uint8_t channel, int16_t value) override {
      switch (_devices[channel].program) {
        case Program::Channels:
          _devices[channel].note.pitchbend = (float)value / (value < 0 ? 8192.f : 8191.f);
          updateChannel(channel);
          break;
      }
    }

    void handleSystemReset() override {
      reset();
      readConfiguration();
    }

    void handleSwitchChannel(uint8_t channel) override {
      _currentChannel = channel;
    }

    void exportSettings(JsonArray json) override {
      for (uint8_t ch = 0; ch < 16; ch++) {
        {
          JsonObject setting = json.add<JsonObject>();
          setting["type"]    = "title";

          char name[16];
          sprintf(name, "Device %d", ch + 1);
          setting["title"] = name;
        }

        if (config.devices[ch].count > 0) {
          JsonObject setting = json.add<JsonObject>();
          setting["type"]    = "text";
          setting["label"]   = "Name";

          char path[64];
          sprintf(path, "devices[%d]/name", ch);
          setting["path"] = path;
        }

        {
          JsonObject setting = json.add<JsonObject>();
          setting["type"]    = "number";
          setting["label"]   = "DMX";
          setting["text"]    = "Channels";
          setting["max"]     = 32;
          setting["input"]   = "select";

          char path[64];
          sprintf(path, "devices[%d]/count", ch);
          setting["path"] = path;
        }

        if (config.devices[ch].count == 0)
          continue;

        {
          JsonObject setting = json.add<JsonObject>();
          setting["type"]    = "number";
          setting["label"]   = "DMX";
          setting["text"]    = "Start Address";
          setting["min"]     = 1;
          setting["max"]     = 512;

          char path[64];
          sprintf(path, "devices[%d]/address", ch);
          setting["path"] = path;
        }

        if (config.devices[ch].count >= 3) {
          JsonObject setting = json.add<JsonObject>();
          setting["type"]    = "colour";
          setting["ruler"]   = true;

          char path[64];
          sprintf(path, "devices[%d]/colour", ch);
          setting["path"] = path;
        }

        for (uint8_t i = 0; i < config.devices[ch].count; i++) {
          JsonObject setting = json.add<JsonObject>();
          setting["type"]    = "number";
          setting["label"]   = "DMX";

          char name[16];
          sprintf(name, "Channel %d", i + 1);
          setting["text"] = name;

          char path[64];
          sprintf(path, "devices[%d]/channels[%d]", ch, i);
          setting["path"] = path;
        }
      }
    }
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
    void loop() {
      if (Device.usb.midi.receive(_midi))
        Device.dispatch(&Device.usb.midi, &_midi);

      if (MIDISerial.receive(_midi))
        Device.dispatch(&Device.usb.midi, &_midi);
    }

  private:
    V2MIDI::Packet _midi{};
  } MIDI;

  class Button : public V2Buttons::Button {
  public:
    Button() : V2Buttons::Button(NULL, PIN_BUTTON) {}

  private:
    void handleDown() override {
      Device.toggleState();
    }
  } Button;
}

auto setup() -> void {
  Serial.begin(9600);

  LED.begin();
  LED.brightnessMax(0.5);

  MIDISerial.begin();
  Device.ports.push_back(&MIDISerial);

  DMX.begin();
  Button.begin();
  Device.begin();
  Device.reset();
  Device.readConfiguration();
}

auto loop() -> void {
  LED.loop();
  MIDI.loop();
  DMX.loop();
  V2Buttons::loop();
  Device.loop();

  if (Device.idle())
    Device.sleep();
}

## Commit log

2026-01-06 Update symbols
    [DMXLEDs.kicad_sch, DMXOut.kicad_sch, MIDIIn.kicad_sch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]
2026-01-12 Update power symbols
    [DMXLEDs.kicad_sch, DMXOut.kicad_sch, MIDIIn.kicad_sch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]
2026-01-14 Update parts
    [DMXLEDs.kicad_sch, DMXOut.kicad_sch, MIDIIn.kicad_sch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]
2026-02-01 Update library
    [MIDIIn.kicad_sch, button-laser.dxf, dmx.kicad_pcb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]
2026-02-02 Support channel LEDs
2026-02-10 Use date as revision
    [dmx.kicad_pcb, dmx.kicad_sch]
2026-02-13 Replace Order_Number
    [dmx.kicad_pcb, dmx.kicad_sch]
2026-02-25 Export stencil
    [DMXLEDs.kicad_sch, DMXOut.kicad_sch, MIDIIn.kicad_sch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]
2026-03-14 Update ESD suppressor
    [dmx.kicad_pcb, dmx.kicad_sch]
2026-03-30 Replace diode
    [DMXLEDs.kicad_sch, DMXOut.kicad_sch, MIDIIn.kicad_sch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]
2026-05-11 Good Bye Imperial
    [DMXLEDs.kicad_sch, DMXOut.kicad_sch, MIDIIn.kicad_sch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]
2026-08-20 Update V2DMX Library
    [back.kicad_pcb, front.kicad_pcb]
